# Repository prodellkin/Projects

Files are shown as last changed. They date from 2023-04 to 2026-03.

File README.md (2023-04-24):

# Projects
Radio&amp;Electronic boards and devices
Meridian 210 - schematic and PCB for UHF board based on TA7358AP IC upgrading Receiver Meridian 210 to support 87-108M band.
Ocean 209-214 - schematic and PCB for UHF board based on TA7358AP/TEA5710 IC upgrading Receiver Ocean 209/214 to support 87-108M band.
Riga 104 - schematic and PCB for UHF board based on TA7358AP IC upgrading Receiver Riga 104 to support 87-108M band.
UHF-1-05S - schematic and PCB for UHF board based on TA7358AP IC upgrading legacy board to support 87-108M band.

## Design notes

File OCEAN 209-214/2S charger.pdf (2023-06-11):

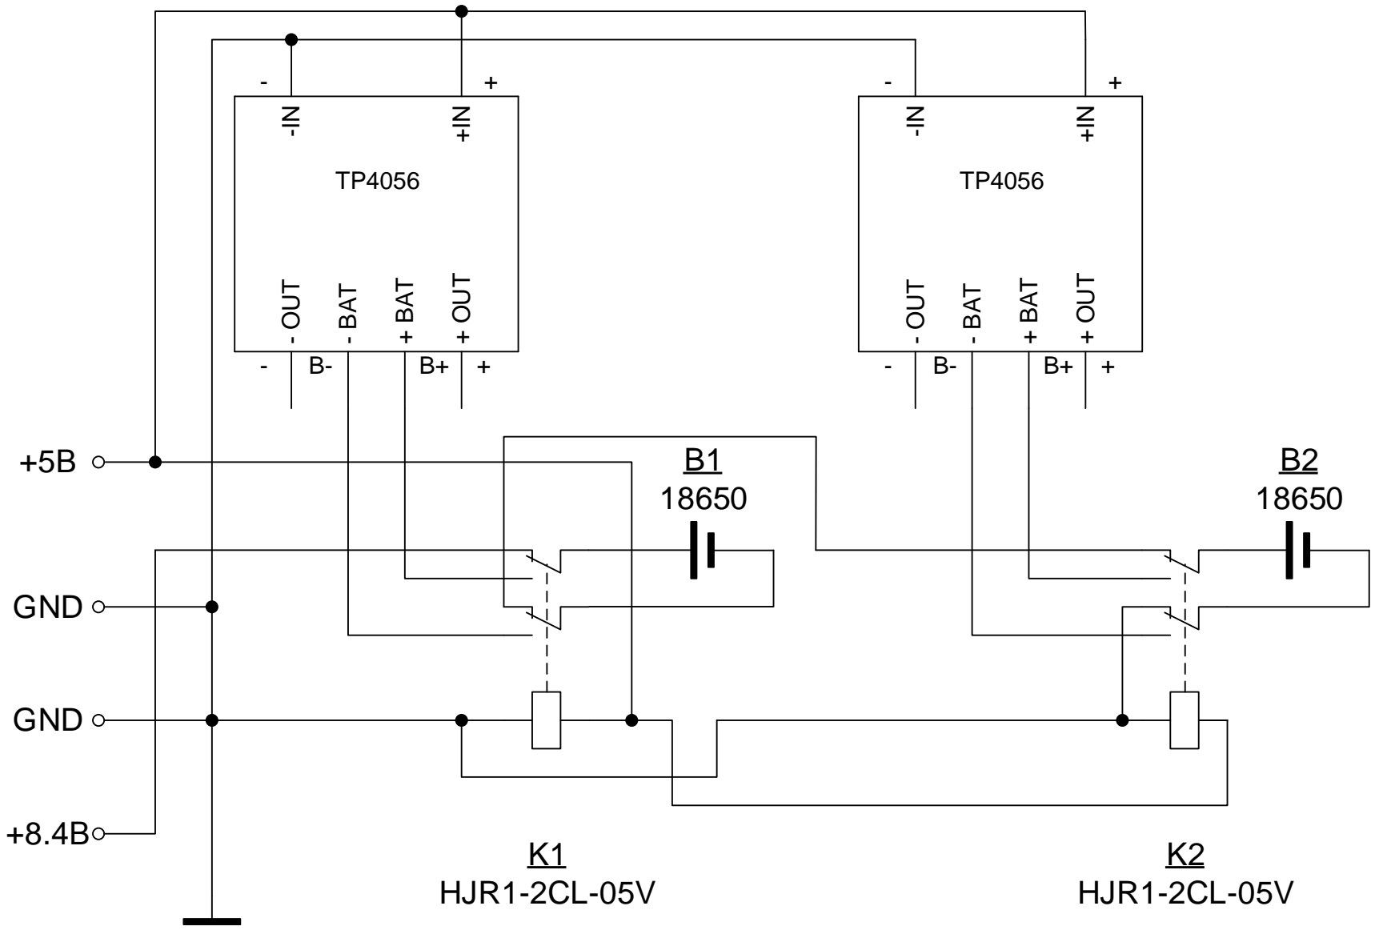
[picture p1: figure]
+ ⁻ OUT; + BAT; + OUT; +IN - BAT; HJR; GND; GND +8.4В
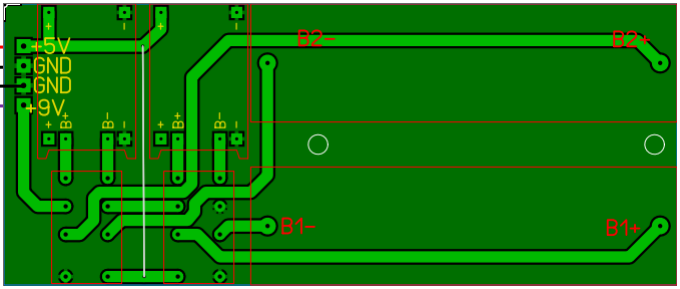
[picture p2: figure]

Вход

+

5

В

Выход

+

9

В

Общий
(земля

)
Общий
(земля

)

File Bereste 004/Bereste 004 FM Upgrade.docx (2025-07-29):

1 этап – демонтаж старого блока.

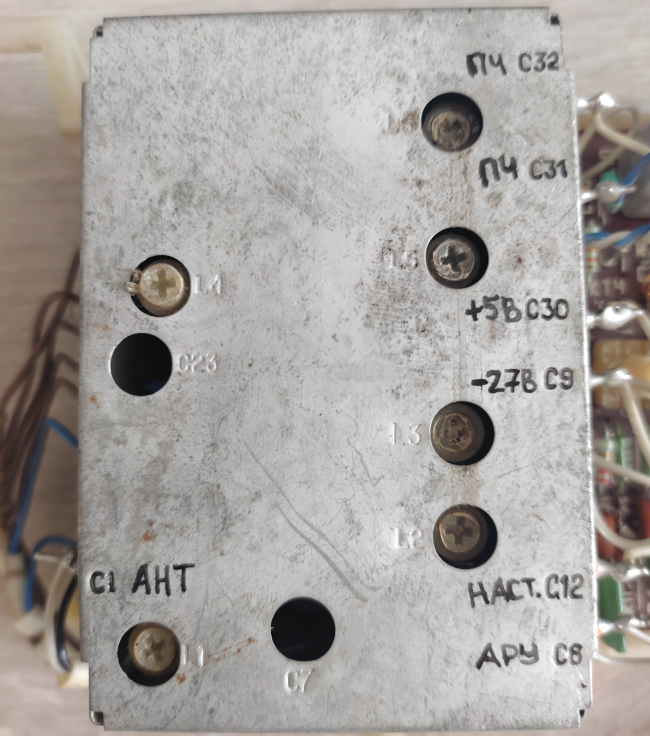
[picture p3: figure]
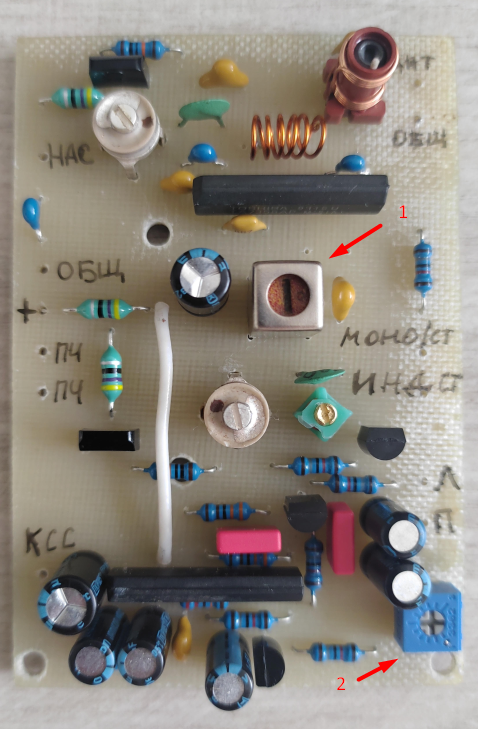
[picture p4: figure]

Отпаиваем и помечаем все контакты, затем выпаивается сам блок вместе с экраном. В будущем не будут использоваться 2 контакта:

АРУ и -27В – не используется, необходимо заизолировать.

2 этап – монтаж нового блока.

Просверливаются отверстия 3 мм по месту для крепления стоек платы. Сначала припаиваются все провода от старого блока УКВ. Примечание:

1) к антенне идет 2 провода, один из которых провод заземления, его при монтаже нового блока необходимо припаять к общему проводу;
2) провод идущий на корпус со стороны платы при монтаже нового блока необходимо припаять к общему проводу;
3) полярность 2-х проводов ПЧ не имеет значения.

Затем припаиваются провода к части стереодекодера в следующей последовательности:

№ | Контакт на новой плате | Контакт на старой плате
1 | МОНО/СТЕРЕО (М/С) | Конт. 10
2 | ИНДИКАЦИЯ СТЕРЕО (ИНД. СТ.) | Конт. 11
3 | Вход стереодекодера (KCC) | КТ10
4 | Выход левого канала (Л) | Конт. 13
5 | Выход правого канала (П) | Конт. 12

Примечание:

1) провода от конт. 11, 12, 13 отпаиваются от контактов и припаиваются к новой плате;
2) провод от конт. 10 НЕ отпаивается! На КТ10 и конт. 10 от новой платы припаивается дополнительный провод.

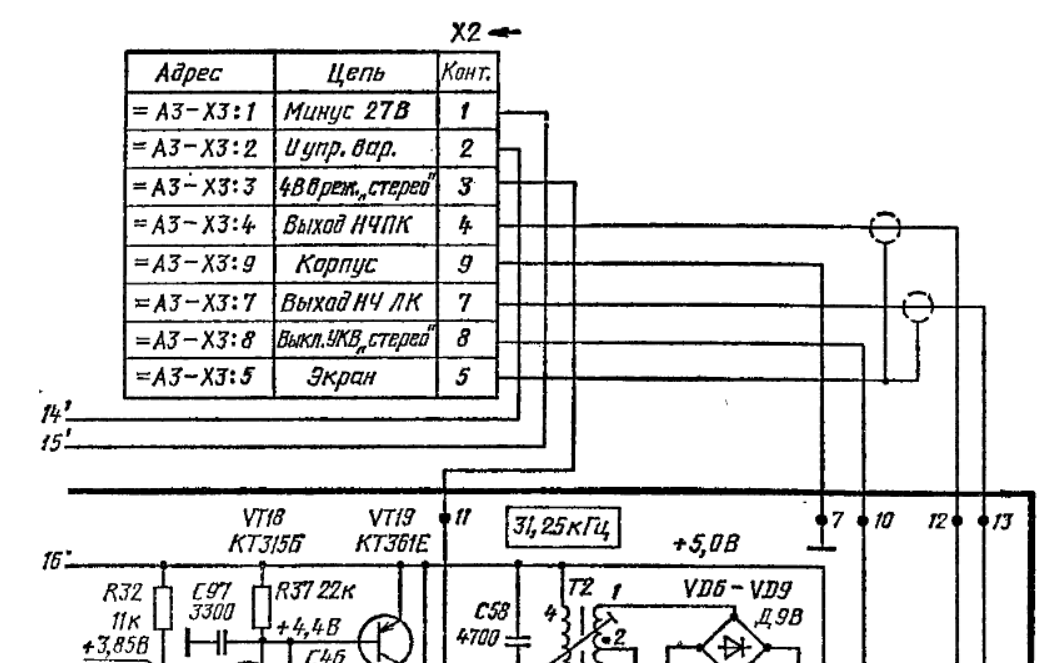
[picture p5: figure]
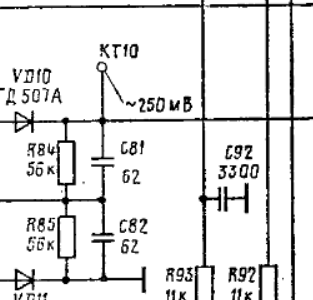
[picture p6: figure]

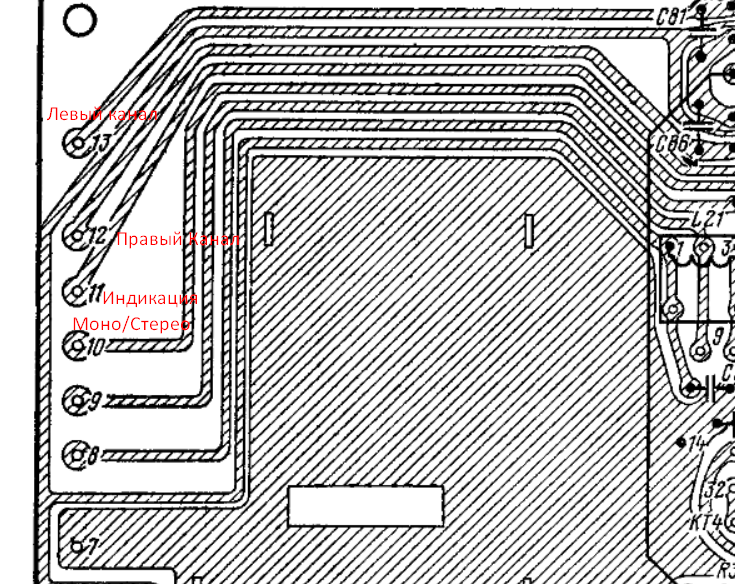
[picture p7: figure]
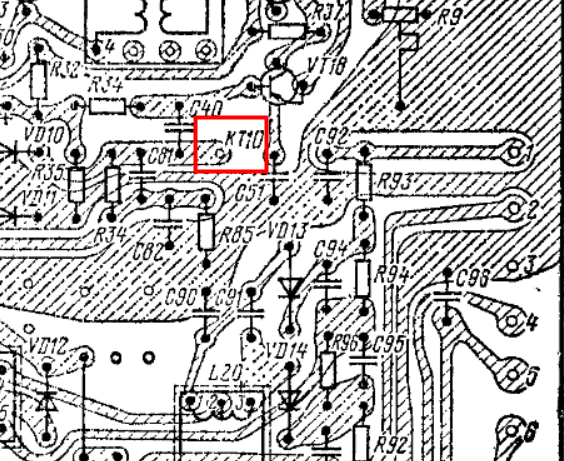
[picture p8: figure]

3 этап – настройка нового блока (при необходимости).

При некорректной работе АПЧ или низком качестве приема необходимо подстроить частоту ПЧ – покрутить сердечник катушки поз.1, необходимо найти положение при котором по индикатору настройки наблюдается максимальное отклонение стрелки вверх.

При некорректной работе стереодекодера (не активируется режим стерео) – покрутить сердечник подстроечного резистора поз.2, необходимо добиться стабильного загорания светодиода СТЕРЕО (должен быть устойчивый и качественный прием станции), необходимо подобрать среднее положение сердечника резистора, при котором индикатор СТЕРЕО горит.

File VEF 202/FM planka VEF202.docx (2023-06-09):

https://forum.guns.ru/forummessage/439/2655638.html

FM приёмник на микросхеме TEA5710

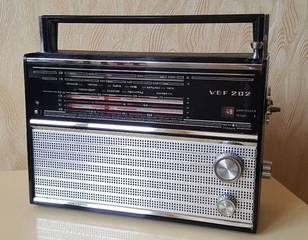
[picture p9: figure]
click for enlarge 893 X 695 89.2 Kb

Решил выложить и мою первую планку, которую я изготовил для VEF приёмника. Идея взята из журнала 'Радио' плюс генератор для подключения к КПЕ. Принцип эго работы уже описал Александр.
Микросхемка старенькая, но она мне нравиться. Есть в этой конструкции свой недостатки - таких как количество радиодеталей, более трудоёмкий процесс согласования и пайки и т.п. Но, с другой стороны, имеет и не мало достоинств по сравнением с цифровым вариантом модуля. Пусть каждый оценивает для себя. Я только могу сказать, что мой товарищ, которому я добавил FM планку, попробовав цифровой вариант, попросил поменять на вот этот. Лично мне собирать и настраивать этот вариант даже больше удовлетворения приносит. А подобрав определённые номиналы резисторов, шкала на линейке ложиться равномерно. Да и середина шкалы находится примерно там, где и должна она находиться.
И так. Сама схема:

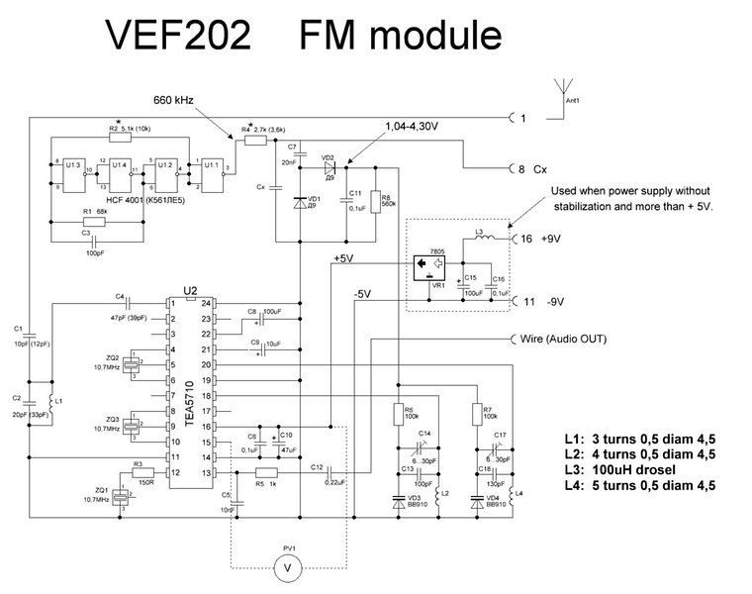
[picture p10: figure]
click for enlarge 1444 X 1140 108.0 Kb

Сам этой схемы не сочинял, а собрал разные идей в одну кучу. Основной источник, кроме выше указанного журнала, был этот: youtube.com (https://www.youtube.com/watch?v=tI-r-BeDLq0)
Но так красиво, как там показано, мне не получалось. Исправил неточности и недочёты. Теперь собирается на раз два. Уже не одну какую планку соорудил.
Пунктиром помеченная часть собирается если питание не стабилизировано или больше 5В. Конденсаторы C14 и C17 для точной настройки. Их можно и не ставить. Тогда необходимо подбирать C13 и C18.
Пунктиром указан Вольтметр используется для настройки преселектора. Место его можно подключить (и оставить) LED диод и сопротивление. Получиться индикатор точной настройки на станцию.
Часть схемы имеет двойные номиналы. В кавычках указаны номиналы, которые есть в большинстве аналогических схем в интернете. А рядом - то, что я реально монтирую. Правда, C2 у меня варьируют от 5 до 20пФ. Тут я каждый раз подгоняю на своём NWT.

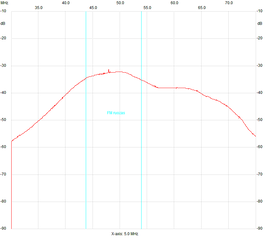
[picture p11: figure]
click for enlarge 828 X 744 15.8 Kb

R2 - определяет частоту генератора. Меняя его номинал можно двигать всю полосу приёма. А при подборе R4 - регулировать полосу приёма. При подборе выше указанных резисторов я добиваюсь равномерной укладке диапазона и чтобы центр совал с центральным местом на линейке шкалы.

Сама платка:

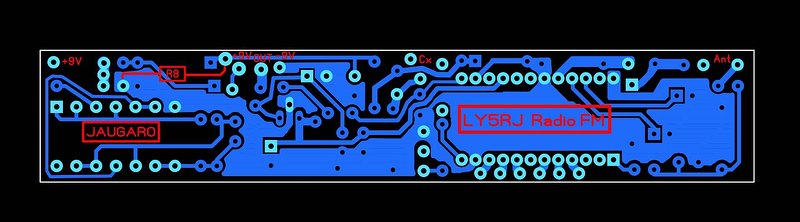
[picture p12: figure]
click for enlarge 1920 X 533 119.3 Kb
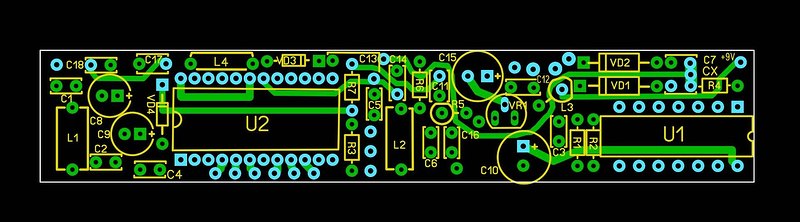
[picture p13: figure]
click for enlarge 1920 X 533 145.3 Kb

Тут она уже в собранном виде:

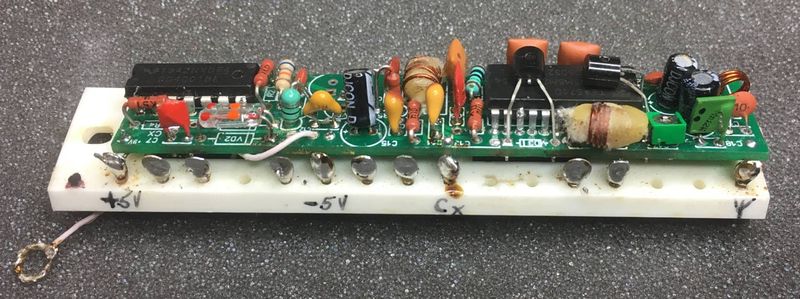
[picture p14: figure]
click for enlarge 1920 X 718 222.5 Kb
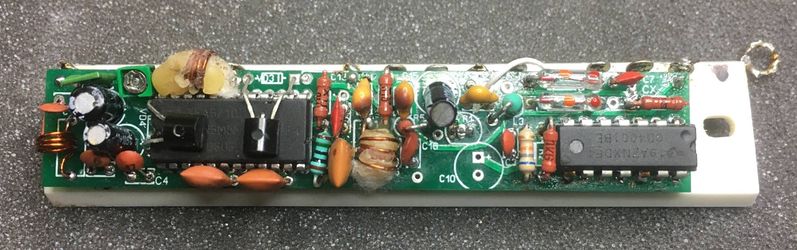
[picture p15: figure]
click for enlarge 1920 X 602 185.2 Kb

FM планка крепится к планке барабана. До того убираем все элементы с её:

Выход звука подключается через барабан селектора диапазонов.

И на последок:
GERBER файлы : drive.google.com (https://drive.google.com/file/d/1DHaM1_9moJCl6rNL8vpKkzjYkamQDfbI/view?usp=sharing)
Схема: drive.google.com (https://drive.google.com/file/d/1Xw-jNQTW3P0Qw9oQIpU2xpCT42s7jg_Q/view?usp=sharing)
Плата: drive.google.com (https://drive.google.com/file/d/1N8k9SrjfMHF3WnHbWFqvNk4WUliZaqPf/view?usp=sharing)

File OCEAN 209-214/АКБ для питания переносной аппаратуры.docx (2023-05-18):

# Универсальный АКБ для питания переносной аппаратуры

# 1 Простой АКБ на базе Li-Ion

Иногда проще и дешевле использовать широко доступные Li-Ion аккумуляторы, чем покупать батарейки для питания переносной радиоаппаратуры. Единственная трудность – размещение Li-Ion аккумуляторов в родном отсеке и их правильная зарядка. На рис 1 представлена схема зарядки-коммутатора.

Рис 1. Принципиальная схема зарядки-коммутатора

В рис 2 изображено изделие в готовом виде, по трудозатратам это за пару часов можно успеть, специальной наладки/калибровки не требуется.

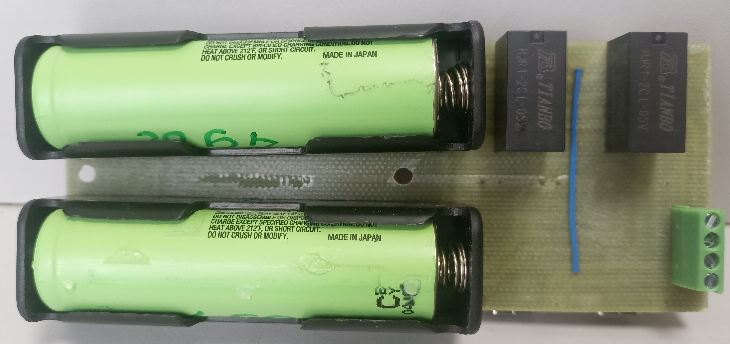
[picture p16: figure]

Рис 2. Готовое изделие

## 1.1 Описание схемы

Основой зарядки является готовый модуль с Алиэкспресса на базе ИМС TP4056, который представляет собой законченный узел управления зарядкой Li-Ion батареи напряжением 4.2В.

Для получения требуемого выходного напряжения набирается необходимое количество Li-Ion аккумуляторов, их коммутация осуществляется с помощью переключающего реле на 2 группы контактов.

При отсутствии входного напряжения +5В обмотки резе не запитаны и своими контактами соединяют Li-Ion аккумуляторы последовательно, обеспечивая необходимое напряжение на выходе платы.

При подаче входного напряжения +5В обмотки резе запитываются и своими контактами подсоединяют каждый Li-Ion аккумулятор параллельно своей плате зарядки, обеспечивая независимую зарядку каждого элемента.

Схема легко масштабируется путем добавления дополнительных Li-Ion аккумуляторов, реле, контроллеров зарядки. При отсутствии зарядки схема не потребляет ток, что повышает время автономной работы.

Схема содержит минимальное количество широко распространённых деталей.

Предусмотрена как зарядка от отдельного блока питания +5В токов не менее 2А, так и от широко распространенных зарядок смартфонов.

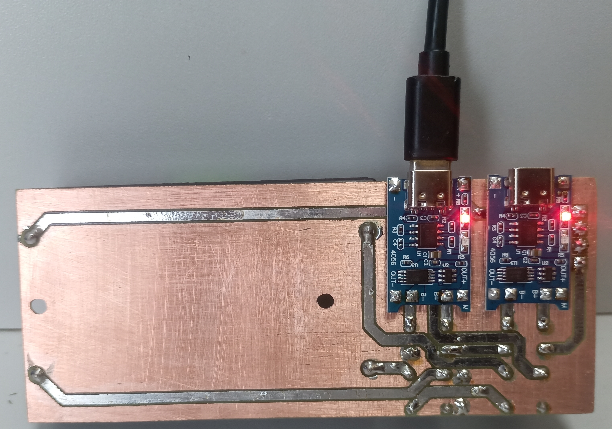
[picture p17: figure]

## 1.2 Печатная плата

Печатная плата изготовлена из одностороннего стеклотекстолита 1,5мм по рис 3 со сплошной заливкой землей. Подключение к плате через клемник с винтовыми зажимами.

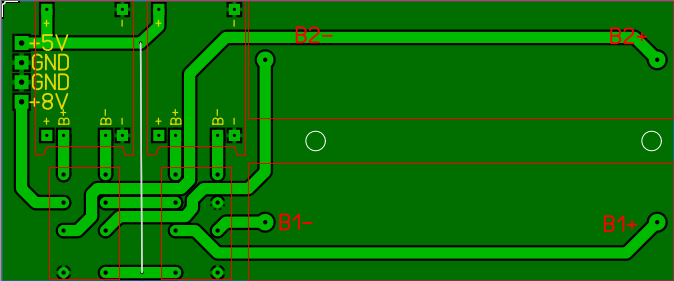
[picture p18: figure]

Рис 3 Печатная плата зарядки-коммутатора

## 1.3 Монтаж

Критическим является монтаж готовых контроллеров зарядки. Предварительно необходимо в отверстия платы впаять отрезки провода 5-7 мм, на которые одеть контроллеры зарядки и припаять их к этим отрезкам провода, чтобы обеспечить отсутствие контакта платы контроллера с дорожками основной платы.

## 1.4 Установка и настройка

Плата устанавливается в отсек АКБ. Последовательность контактов отличается от оригинальной платы (сверху вниз: +5В (вход зарядки), общий (земля), общий (земля), +8.4В(выход питания)), крепление винтовым зажимом.

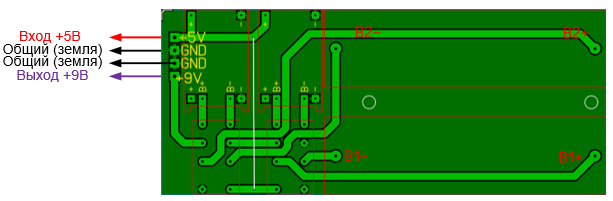
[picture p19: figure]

Настройка блока не требуется.

## 1.5 Возможные замены

Плату контроллера зарядки можно использовать любую, главное, чтобы она была рассчитана на зарядку 1 Li-Ion элемента.

Реле любые, с двумя группами переключающихся контактов с напряжением обмотки 5В.

## 1.6 Опыт при эксплуатации

Ток зарядки определяется параметрами платы контроллера, обычно 500-1000мА. Индикация процесса зарядки и его окончания реализована на плате контроллера 2-мя светодиодами.

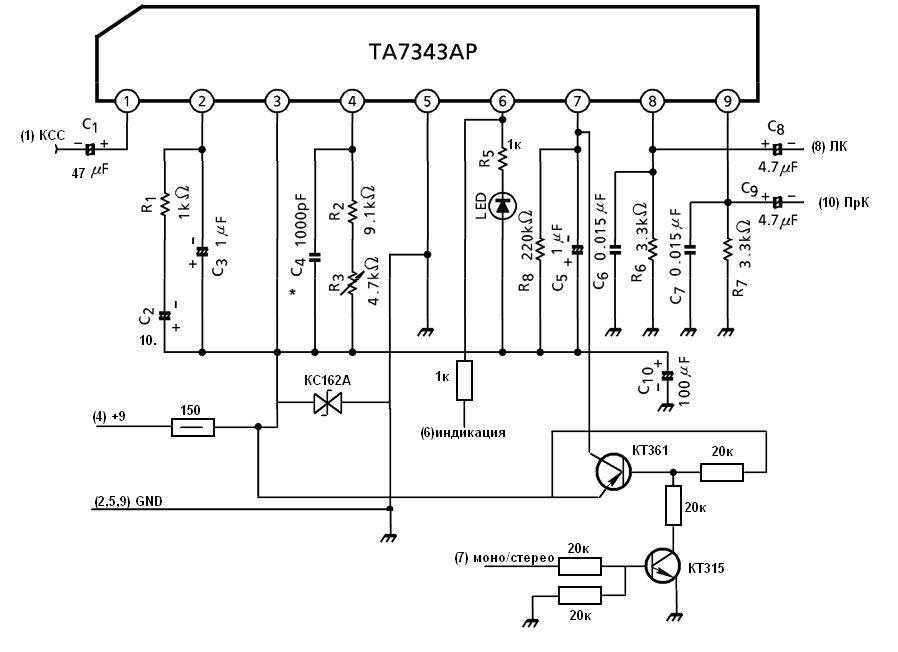
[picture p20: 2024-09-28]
MPX/Схема.png

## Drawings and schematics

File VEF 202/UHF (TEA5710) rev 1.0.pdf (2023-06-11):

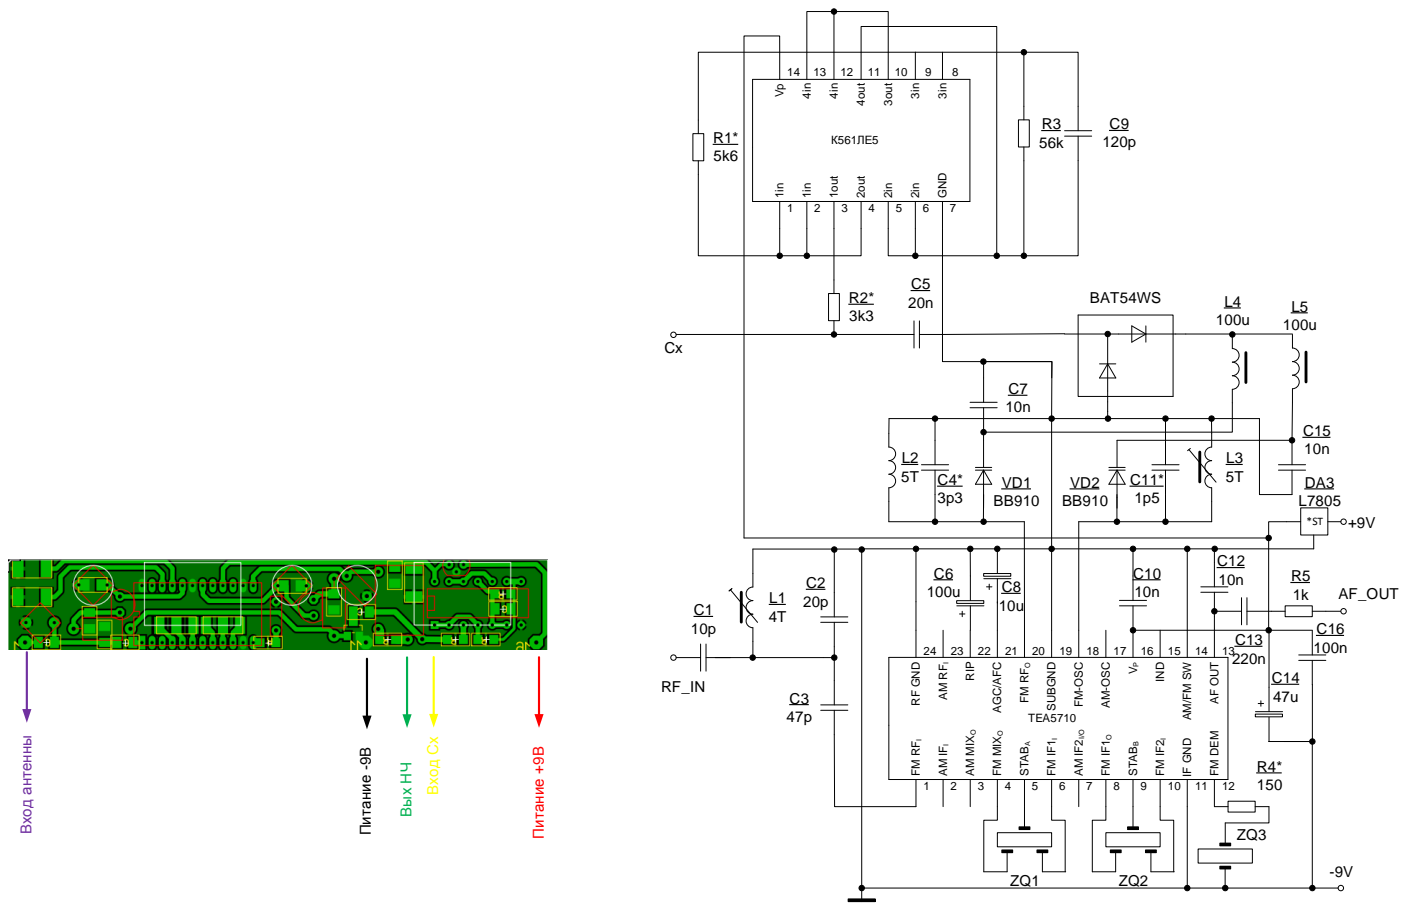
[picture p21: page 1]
TEA5710; FM RFI; AM MIXO; FM MIXO; STABA; 12 IF GND; FM DEM; 13 RIP AM RFI; RF GND; SUBGND; FM RFO; AGC/AFC; AM-OSC; FM-OSC; AF OUT; IND; AM IFI; STABB; _OUT; Вых НЧ; Вход Сх; Питание +9В; Вход антенны; Питание -9В; 1out; 2out; 3out; 4out; GND; BAT54WS

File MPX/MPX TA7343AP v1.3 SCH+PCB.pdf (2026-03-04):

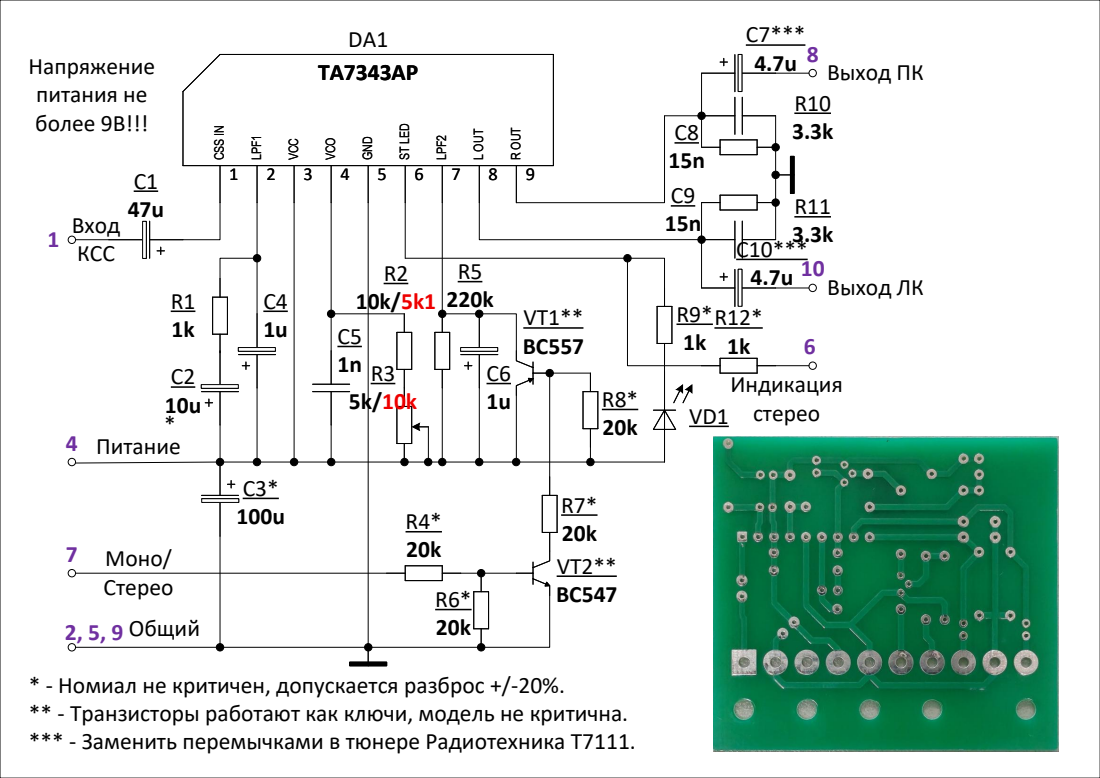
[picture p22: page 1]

* - Номиал не критичен, допускается разброс +/-20%.
** - Транзисторы работают как ключи, модель не критична.
*** - Заменить перемычками в тюнере Радиотехника Т7111.

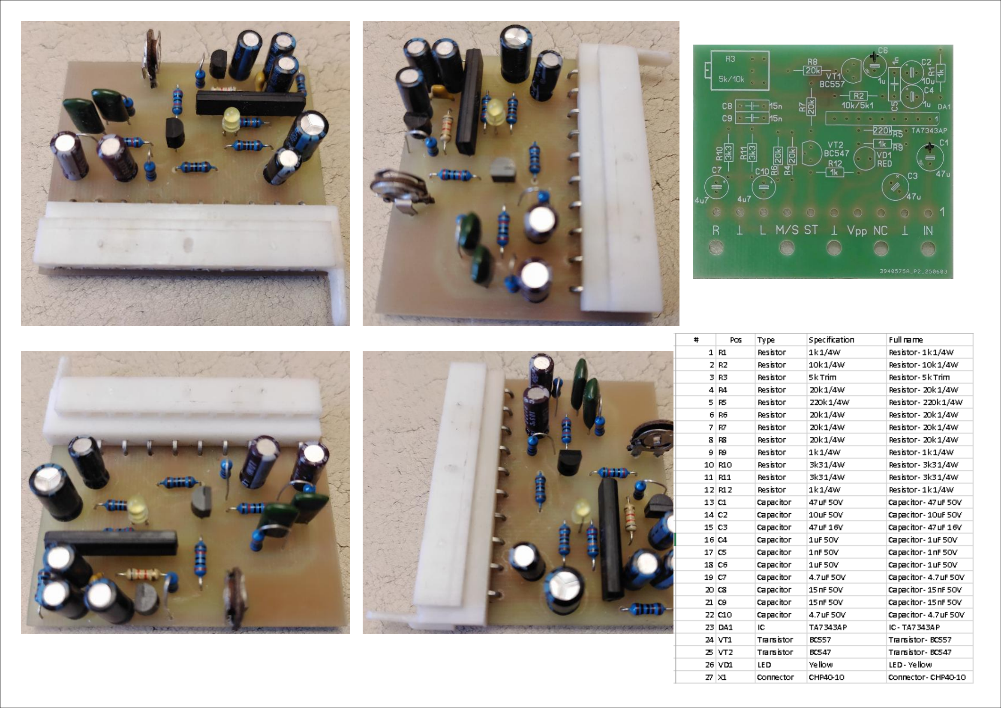
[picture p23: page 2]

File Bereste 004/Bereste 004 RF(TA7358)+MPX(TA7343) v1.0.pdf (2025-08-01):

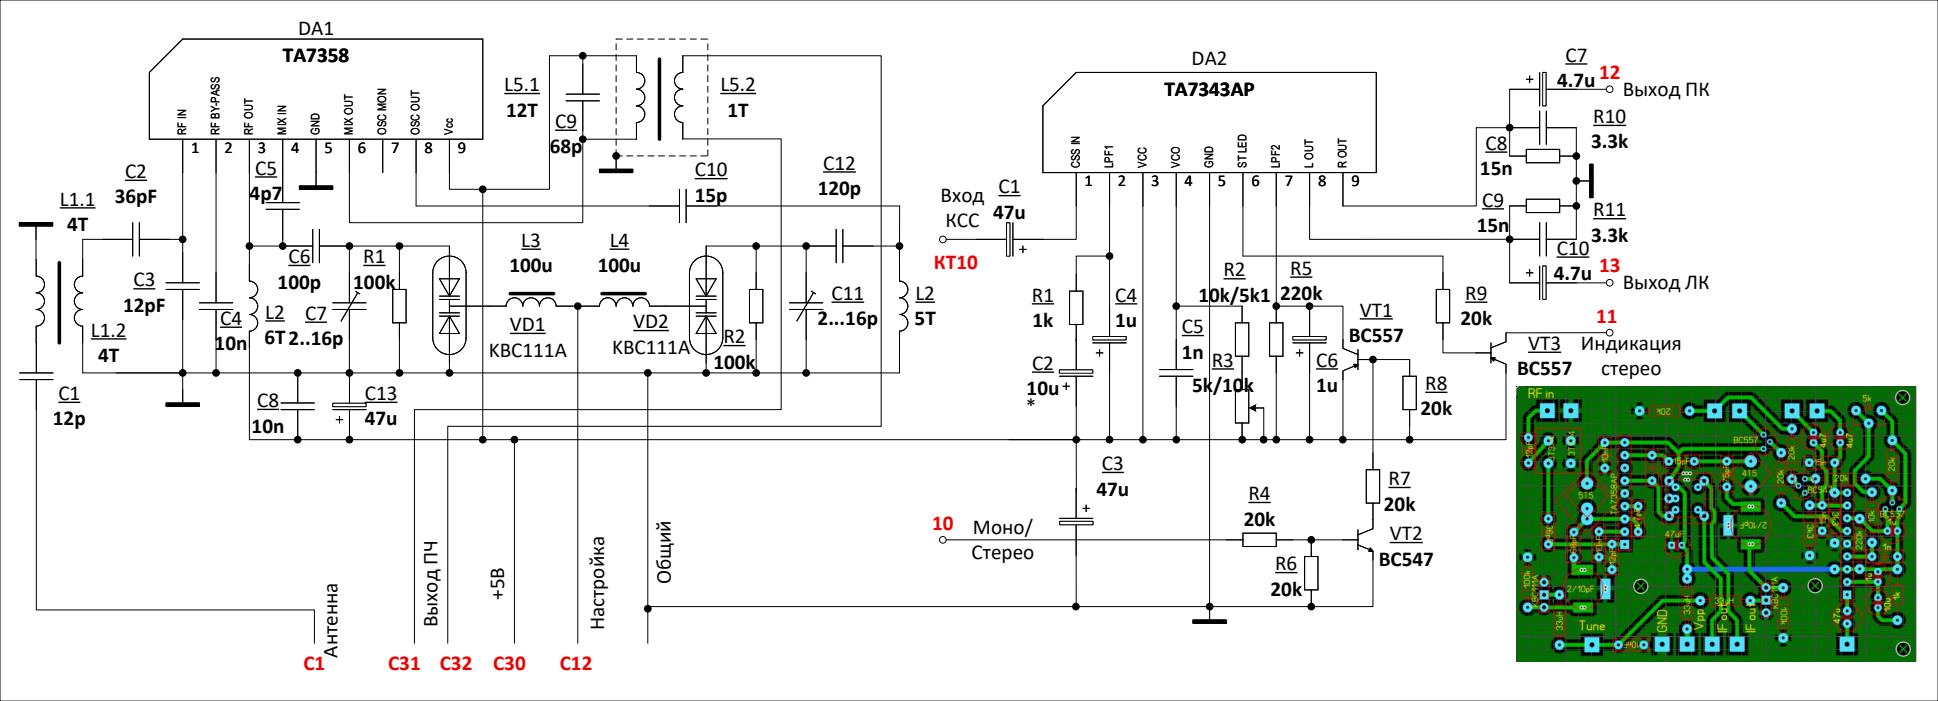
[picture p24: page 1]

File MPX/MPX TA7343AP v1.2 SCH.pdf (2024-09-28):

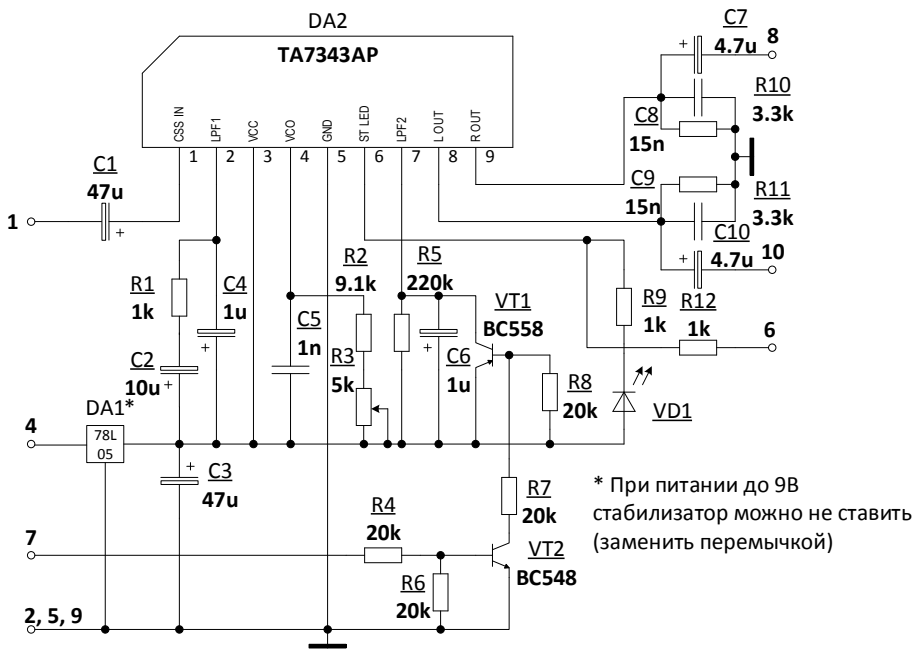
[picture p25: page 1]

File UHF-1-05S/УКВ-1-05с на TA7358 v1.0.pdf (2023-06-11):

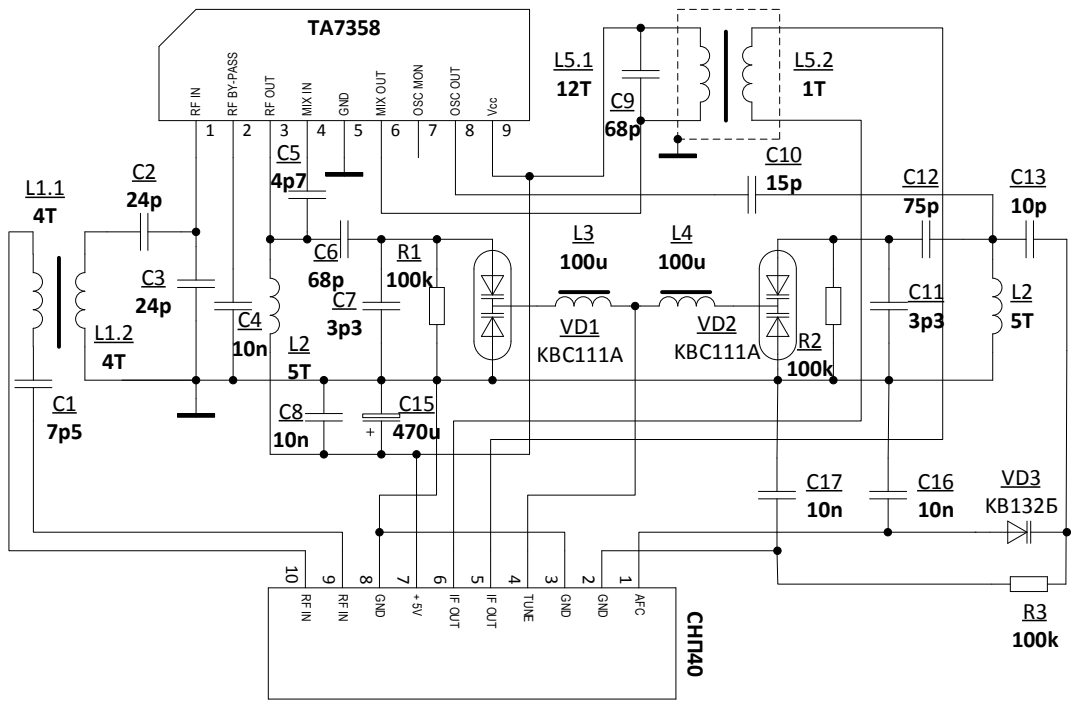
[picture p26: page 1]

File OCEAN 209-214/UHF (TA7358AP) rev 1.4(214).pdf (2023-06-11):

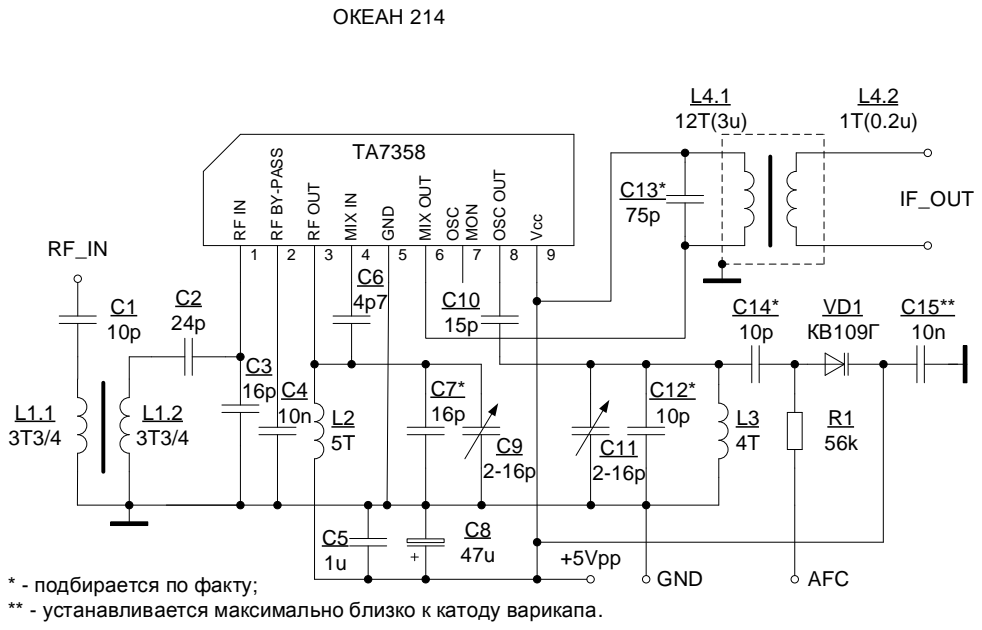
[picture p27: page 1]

* - подбирается по факту;
** - устанавливается максимально близко к катоду варикапа.

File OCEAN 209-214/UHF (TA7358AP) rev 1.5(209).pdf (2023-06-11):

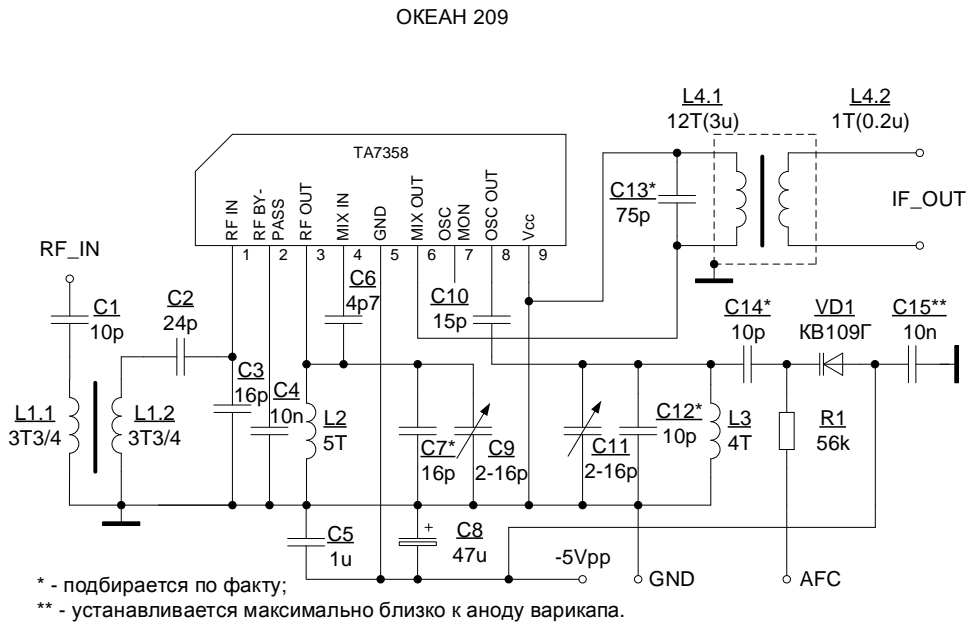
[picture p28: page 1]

* - подбирается по факту;
** - устанавливается максимально близко к аноду варикапа.

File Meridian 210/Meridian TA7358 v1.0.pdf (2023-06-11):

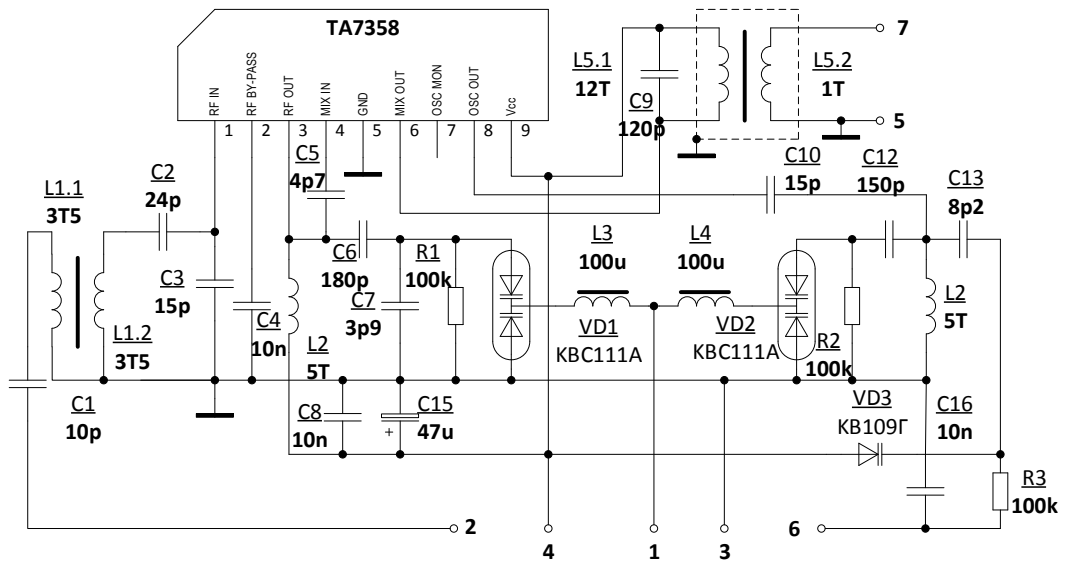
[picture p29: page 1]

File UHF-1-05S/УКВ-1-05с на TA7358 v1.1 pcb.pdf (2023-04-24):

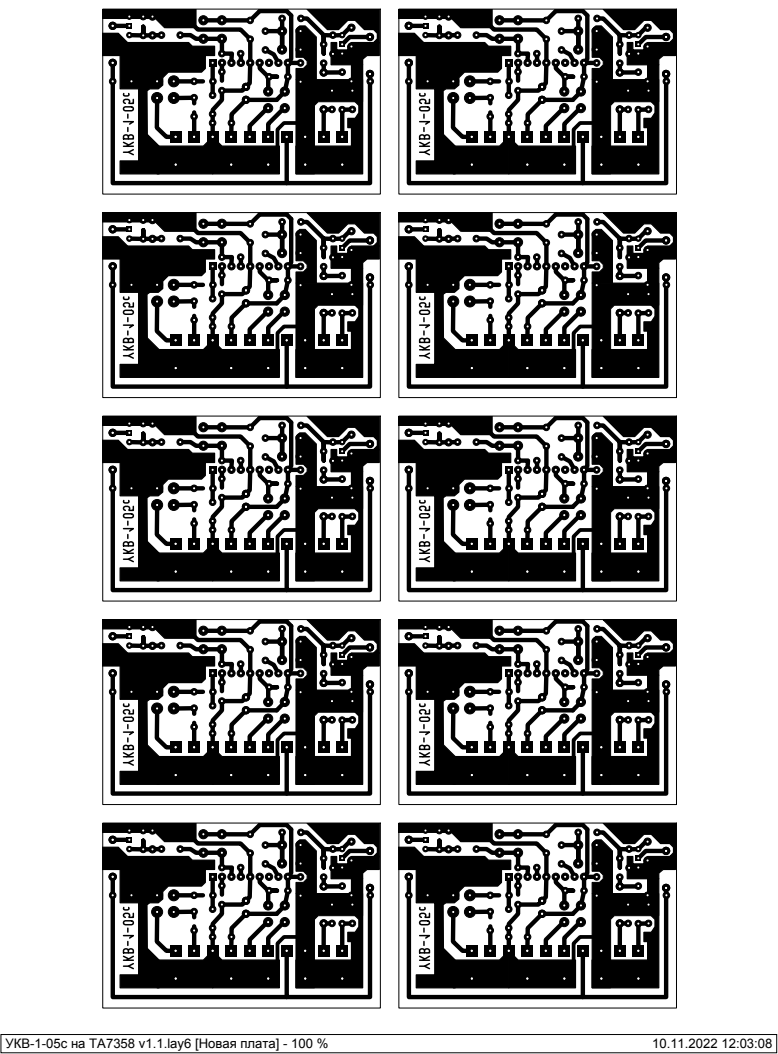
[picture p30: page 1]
УКВ-1-05с на TA7358 v1.1.lay6 [Новая плата] - 100 %
